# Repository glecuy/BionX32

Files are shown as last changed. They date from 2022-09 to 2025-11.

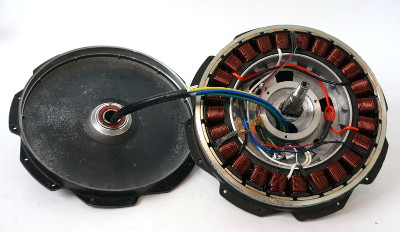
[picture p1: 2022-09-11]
bionx_motor.jpg

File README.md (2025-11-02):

# BionX32  stm32 controller for BionX ebike motor

The BionX motor has originally a built-in controller. This project aims to replace embedde electronics by an external controller.
Regular 24V controller with square waves doesn't provide good enough results, this is a new attempt with a FOC implementation.

## Project Content

3 phases output,

3 hall sensors input,

One Shunt current measurement,

Interface for S866 Display.

PAS input,

Brake input

Core code is generated thanks to ST micro graphical tools. (X-CUBE-MCSDK)
then adapted to STM32F103C8Tx

## Hardware description

STM32 module
MOSFET module
Main pcb
S866 display

## Credits  & Resources
STM32CubeIDE

STM32 MC SDK (motor control software development kit) : Gived up (Did not work for me)

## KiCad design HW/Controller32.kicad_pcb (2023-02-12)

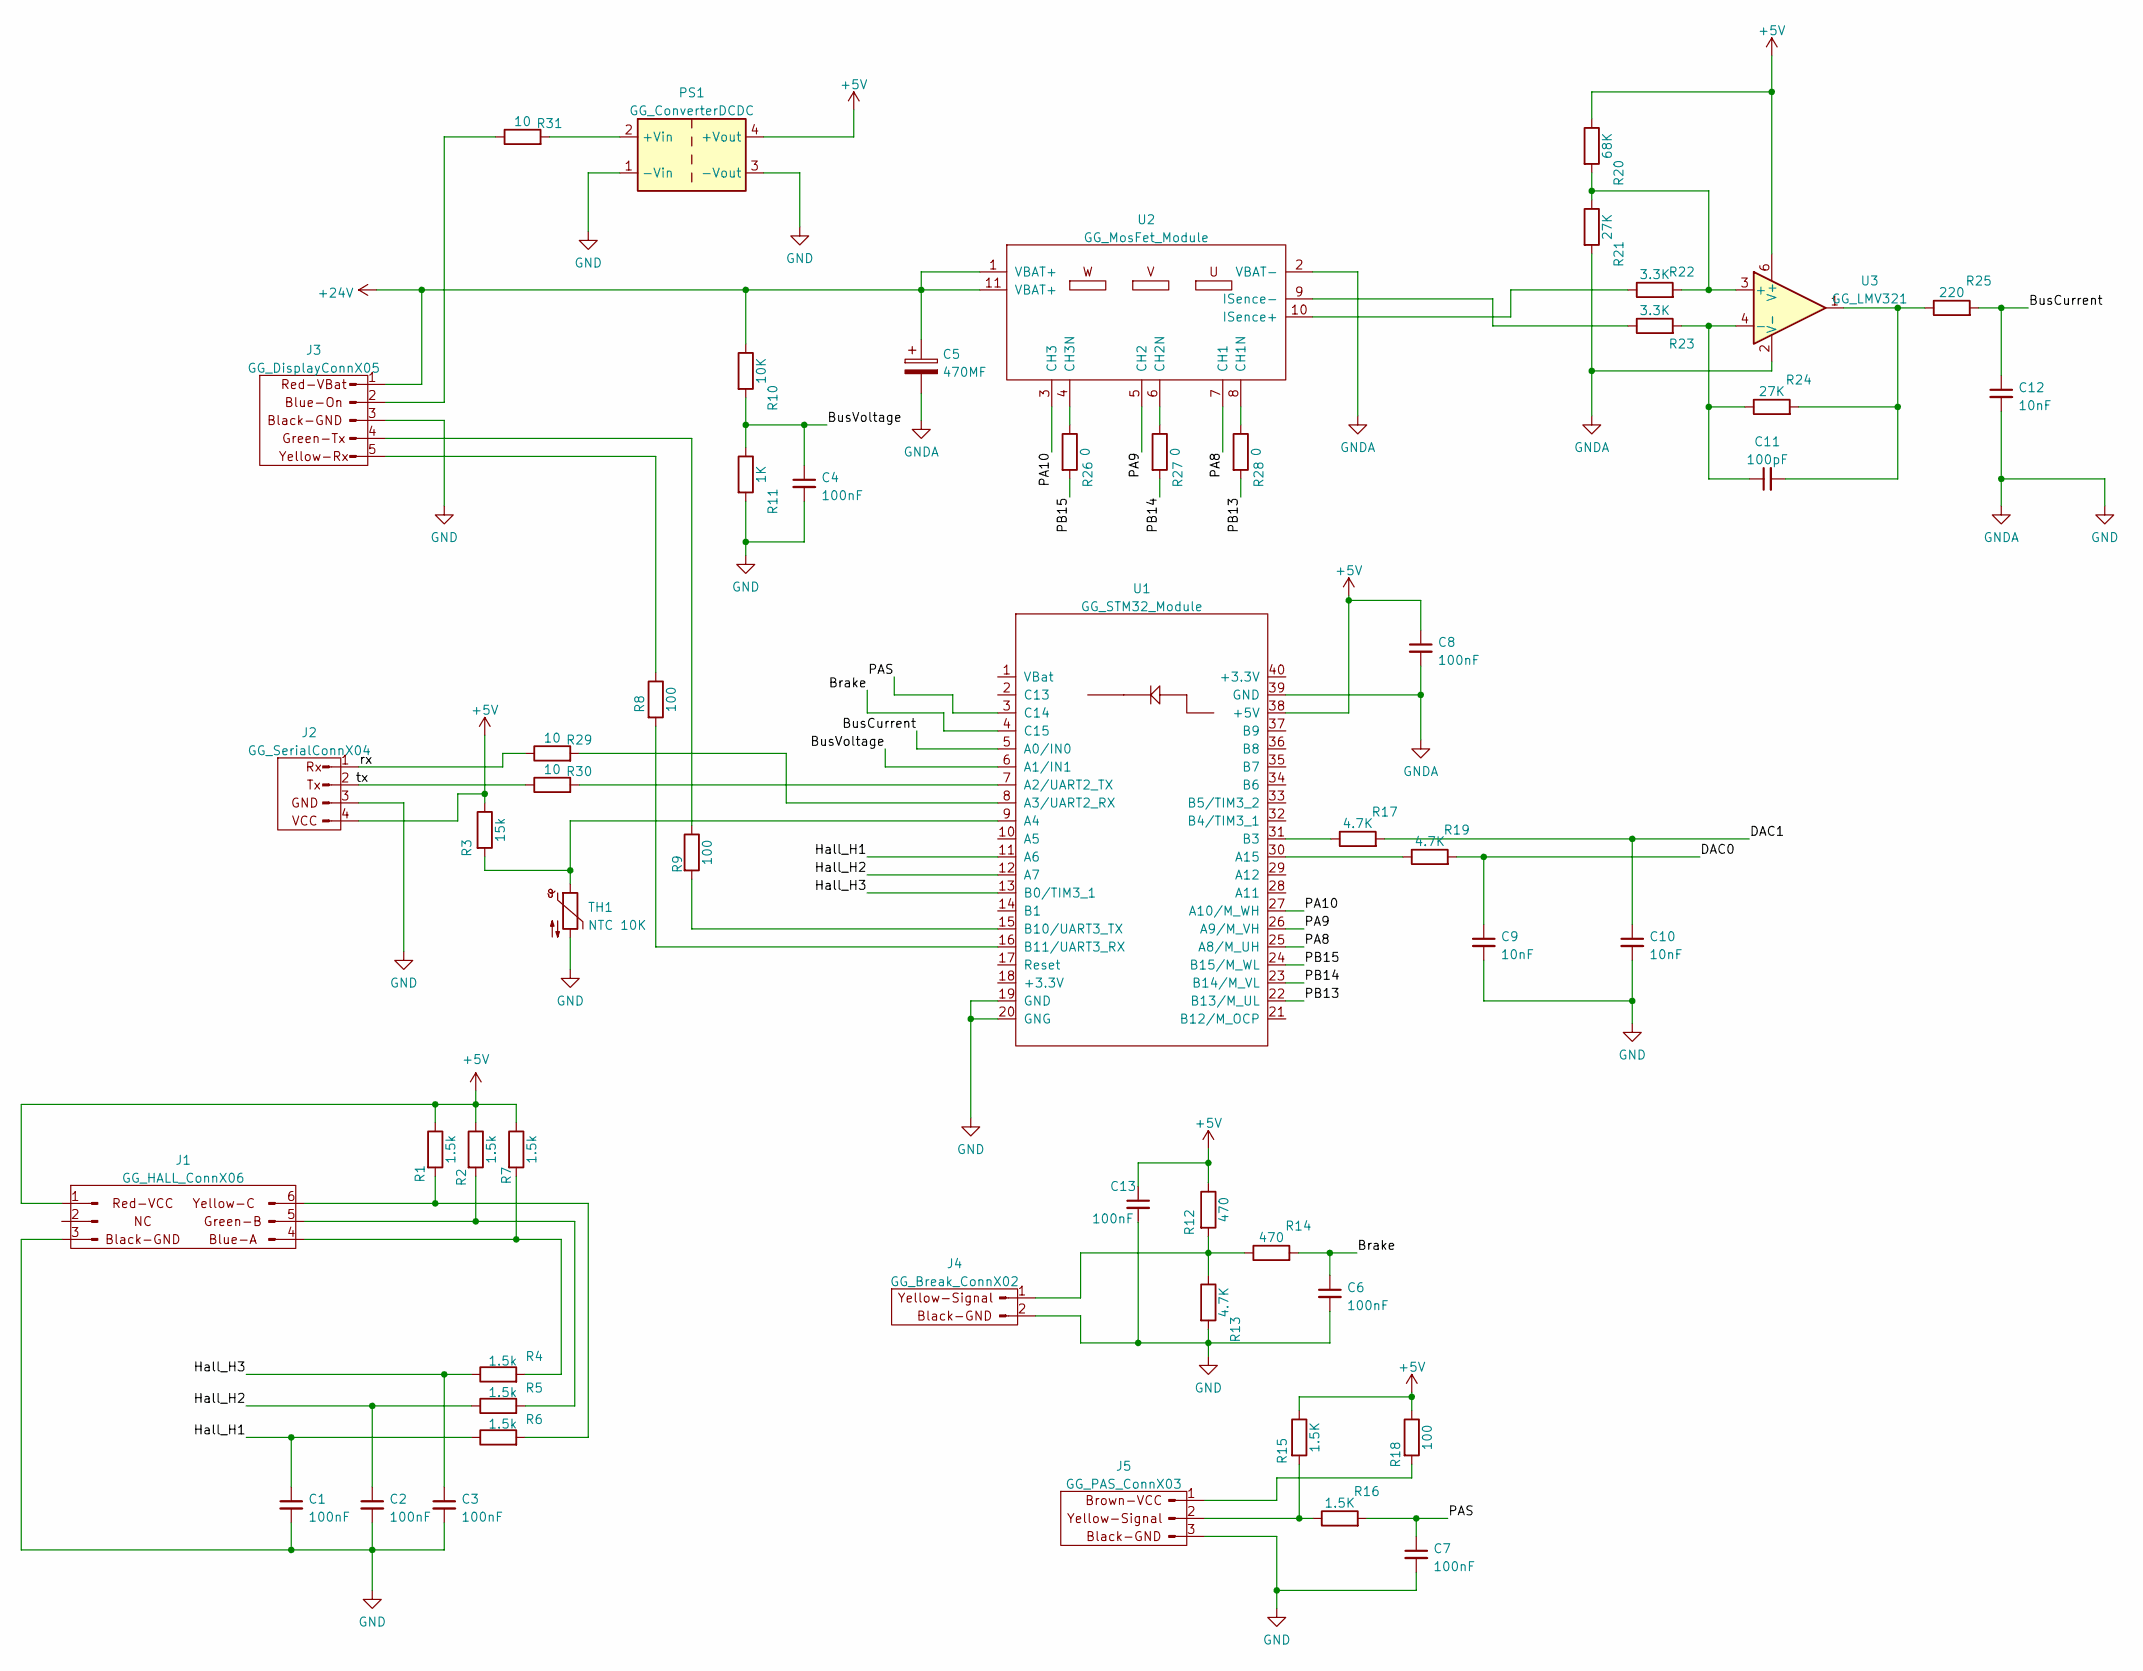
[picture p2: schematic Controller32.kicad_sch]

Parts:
C1, C2, C3, C4, C6, C7, C8, C13: 100nF; GG_C_0805
C5: 470MF; GG_CP_L30.0mm_D15.0mm_Horizontal
C9, C10, C12: 10nF; GG_C_0805
C11: 100pF; GG_C_0805
J1: GG_HALL_ConnX06; GG_6Wires_P2.54mm
J2: GG_SerialConnX04; GG_Serial04_P2.54mm
J3: GG_DisplayConnX05; GG_5Wires_P2.54mm
J4: GG_Break_ConnX02; GG_2Wires_P2.54mm
J5: GG_PAS_ConnX03; GG_3Wires_P2.54mm
PS1: GG_ConverterDCDC; GG_X0018_DCDC
R1, R2, R4, R5, R6, R7: 1.5k; GG_R_1206
R3: 15k; GG_R_1206
R8, R9, R18: 100; GG_R_1206
R10: 10K; GG_R_1206
R11: 1K; GG_R_1206
R12, R14: 470; GG_R_1206
R13, R17, R19: 4.7K; GG_R_1206
R15, R16: 1.5K; GG_R_1206
R20: 68K; GG_R_1206
R21, R24: 27K; GG_R_1206
R22, R23: 3.3K; GG_R_1206
R25: 220; GG_R_1206
R26, R27, R28: 0; GG_R_1206
R29, R30, R31: 10; GG_R_1206
TH1: NTC 10K; GG_2Wires_P2.54mm
U1: GG_STM32_Module; GG_STM32_DIP-40
U2: GG_MosFet_Module; GG_MOSFET_Moule
U3: GG_LMV321; SOT-23-6_Handsoldering

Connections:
+5V: C8.1, C13.1, J1.1, J2.4, PS1.4 (+Vout), R1.1, R2.1, R3.1, R7.1, R12.1, R15.1, R18.1, R20.1, U1.38 (+5V), U3.6 (V+)
+24V: C5.1, J3.1, R10.1, U2.1 (VBAT+), U2.11 (VBAT+)
/Brake: C6.1, R14.2, U1.4 (C15)
/BusCurrent: C12.1, R25.2, U1.5 (A0/IN0)
/BusVoltage: C4.1, R10.2, R11.1, U1.6 (A1/IN1)
/DAC0: C9.1, R19.2
/DAC1: C10.1, R17.2
/Hall_H1: C1.1, R6.1, U1.11 (A6)
/Hall_H2: C2.1, R5.1, U1.12 (A7)
/Hall_H3: C3.1, R4.1, U1.13 (B0/TIM3_1)
/PA8: U1.25 (A8/M_UH), U2.7 (CH1)
/PA9: U1.26 (A9/M_VH), U2.5 (CH2)
/PA10: U1.27 (A10/M_WH), U2.3 (CH3)
/PAS: C7.1, R16.2, U1.3 (C14)
/PB13: R28.2, U1.22 (B13/M_UL)
/PB14: R27.2, U1.23 (B14/M_VL)
/PB15: R26.2, U1.24 (B15/M_WL)
/rx: J2.1, R29.1
GND: C1.2, C2.2, C3.2, C4.2, C5.2, C6.2, C7.2, C8.2, C9.2, C10.2, C12.2, C13.2, J1.3, J2.3, J3.3, J4.2, J5.3, PS1.1 (-Vin), PS1.3 (-Vout), R11.2, R13.2, R21.2, TH1.2, U1.19 (GND), U1.20 (GNG), U1.39 (GND), U2.2 (VBAT-), U3.2 (V-)
unnamed: C11.1, R23.2, R24.1, U3.4 (-)
unnamed: C11.2, R24.2, R25.1, U3.1
unnamed: J1.4, R4.2, R7.2
unnamed: J1.5, R2.2, R5.2
unnamed: J1.6, R1.2, R6.2
unnamed: J2.2, R30.1
unnamed: J3.2, R31.1
unnamed: J3.4, R9.1
unnamed: J3.5, R8.1
unnamed: J4.1, R12.2, R13.1, R14.1
unnamed: J5.1, R18.2
unnamed: J5.2, R15.2, R16.1
unnamed: PS1.2 (+Vin), R31.2
unnamed: R3.2, TH1.1, U1.9 (A4)
unnamed: R8.2, U1.16 (B11/UART3_RX)
unnamed: R9.2, U1.15 (B10/UART3_TX)
unnamed: R17.1, U1.31 (B3)
unnamed: R19.1, U1.30 (A15)
unnamed: R20.2, R21.1, R22.2, U3.3 (+)
unnamed: R22.1, U2.10 (ISence+)
unnamed: R23.1, U2.9 (ISence-)
unnamed: R26.1, U2.4 (CH3N)
unnamed: R27.1, U2.6 (CH2N)
unnamed: R28.1, U2.8 (CH1N)
unnamed: R29.2, U1.8 (A3/UART2_RX)
unnamed: R30.2, U1.7 (A2/UART2_TX)

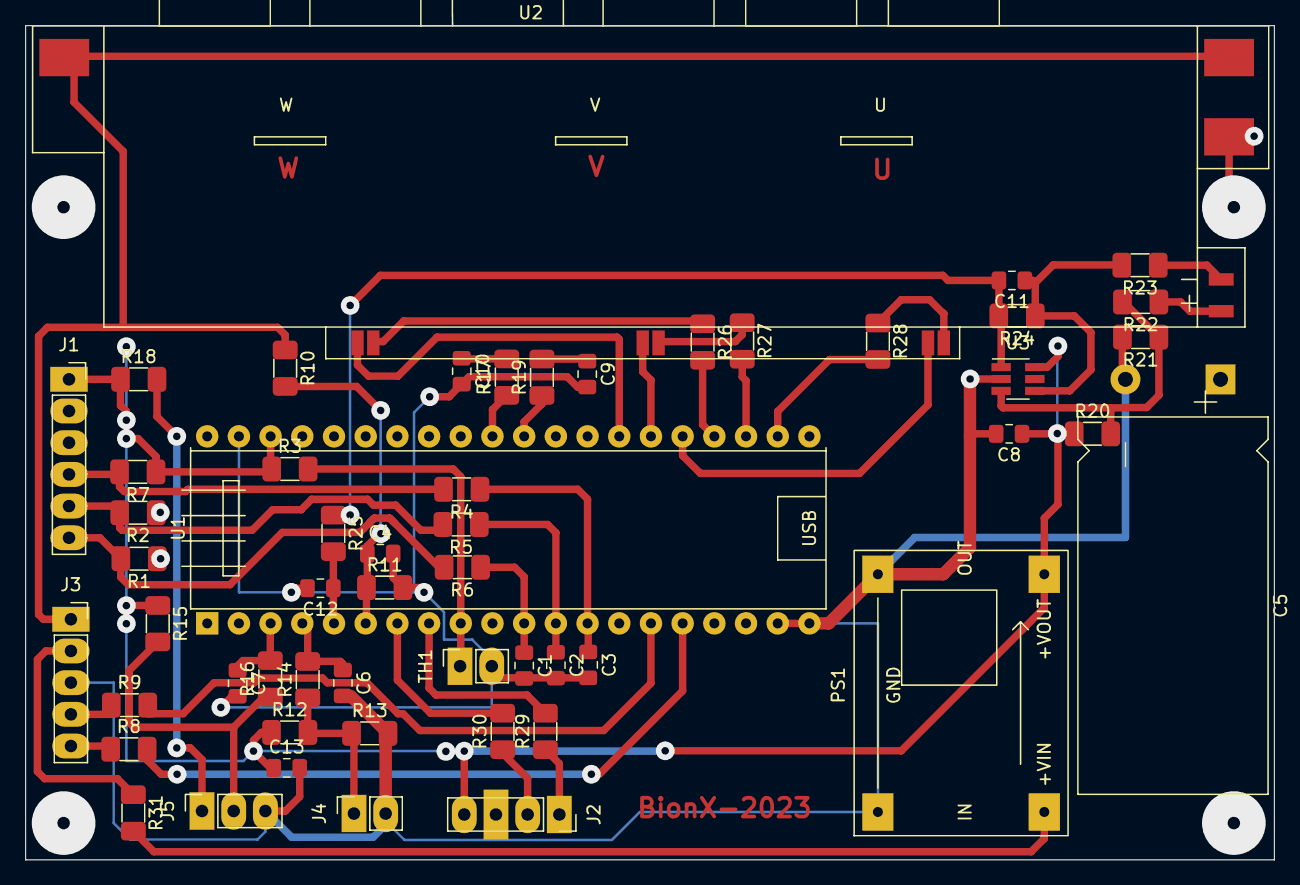
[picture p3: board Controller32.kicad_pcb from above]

Board: 2 copper layers, 100.1 x 66.9 mm, 54 parts (0 on the bottom side), 45 nets.

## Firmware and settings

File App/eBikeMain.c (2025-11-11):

/*
 *
 *
 ***********************************************************************/

#include <stdio.h>
#include <stdbool.h>
#include <stdlib.h>

#include "main.h"
#include "stm32f1xx_ll_gpio.h"

#include "UART_Printf.h"
#include "busVoltageSensor.h"
#include "eBikeMain.h"
#include "motorControl.h"

#include "display.h"

extern TIM_HandleTypeDef htim1;
extern TIM_HandleTypeDef htim2;
extern TIM_HandleTypeDef htim3;
extern TIM_HandleTypeDef htim4;
extern DMA_HandleTypeDef hdma_tim1_up;
extern DMA_HandleTypeDef hdma_tim1_ch4_trig_com;

extern ADC_HandleTypeDef hadc1;
//extern ADC_HandleTypeDef hadc2;

uint32_t ADC_ResultBuffer[4];


// Motor
static uint16_t PreviousHallState;
static uint32_t HallError;
static uint16_t HallTicks;
static uint32_t HallCycles;
static uint16_t PreviousHallTicks;

//static uint16_t SpaceSectorCnt;

static uint32_t BusVoltage, BoardTemperature, MotorTemperature;
static uint32_t PhaseCurrent;


static uint16_t HallState;

static inline void disable_pwm(void) {
  CLEAR_BIT(TIM1->BDTR, TIM_BDTR_MOE);
}

static inline void enable_pwm(void) {
  SET_BIT(TIM1->BDTR, TIM_BDTR_MOE);
}

static inline bool isSpaceVectorMode(void) {
    return ( HallTicks < 30000 && HallCycles > 100 );
    //return false;
}

void eBikeInit(void){
    GPIO_InitTypeDef GPIO_InitStruct = {0};

    // Start Timer 1
    if(HAL_TIM_Base_Start_IT(&htim1) != HAL_OK)
    {
        /* Counter Enable Error */
        Error_Handler();
    }

    HAL_TIM_PWM_Start(&htim1, TIM_CHANNEL_1);
    HAL_TIMEx_PWMN_Start(&htim1, TIM_CHANNEL_1); // turn on complementary channel
    HAL_TIM_PWM_Start(&htim1, TIM_CHANNEL_2);
    HAL_TIMEx_PWMN_Start(&htim1, TIM_CHANNEL_2);
    HAL_TIM_PWM_Start(&htim1, TIM_CHANNEL_3);
    HAL_TIMEx_PWMN_Start(&htim1, TIM_CHANNEL_3);

    //TIM1->CR2 = _VAL2FLD(TIM_CR2_MMS, 0b111); // OC1REF signal is used as trigger output (TRGO)
    //TIM1->CR2 = _VAL2FLD(TIM_CR2_MMS, 0b010); // The update event is selected as trigger output (TRGO)

#if 1
    // Start Timer 2 (DAC output)
    HAL_TIM_IC_Start_IT(&htim2, TIM_CHANNEL_1);
    //HAL_TIM_IC_Start_IT(&htim2, TIM_CHANNEL_2);
    //HAL_TIM_IC_Start_IT(&htim2, TIM_CHANNEL_3);

    // Start Timer 3
    //TIM3->PSC = 250;
    HAL_TIM_Base_Start_IT(&htim3);
    HAL_TIMEx_HallSensor_Start_IT(&htim3);
#endif

    //set initial PWM values
    TIM1->CCR1 = 1023;
    TIM1->CCR2 = 1023;
    TIM1->CCR3 = 1023;

    TIM1->CCR4 = 1;

    // App tick timer
    // See https://deepbluembedded.com/stm32-timer-calculator/
    // Updatefrequency = TIM clk/((PSC+1)*(ARR+1))
    //HAL_TIM_Base_Start_IT(&htim4);

    // ***TIM3 GPIO Configuration
    //PA6     ------> TIM3_CH1
    //PA7     ------> TIM3_CH2
    //PB0     ------> TIM3_CH3


    GPIO_InitStruct.Pin = Hall_H1_Pin|Hall_H2_Pin;
    GPIO_InitStruct.Mode = GPIO_MODE_INPUT;
    GPIO_InitStruct.Pull = GPIO_NOPULL;
    HAL_GPIO_Init(GPIOA, &GPIO_InitStruct);

    GPIO_InitStruct.Pin = Hall_H3_Pin;
    GPIO_InitStruct.Mode = GPIO_MODE_INPUT;
    GPIO_InitStruct.Pull = GPIO_NOPULL;
    HAL_GPIO_Init(Hall_H3_GPIO_Port, &GPIO_InitStruct);

    // Lock pins
    LL_GPIO_LockPin(Hall_H3_GPIO_Port, Hall_H3_Pin);
    LL_GPIO_LockPin(Hall_H1_GPIO_Port, Hall_H1_Pin);
    LL_GPIO_LockPin(Hall_H2_GPIO_Port, Hall_H2_Pin);

    MotorDriveInit();

    displayInit();
}

void HAL_TIM_OC_DelayElapsedCallback(TIM_HandleTypeDef *htim){
    if ( htim->Instance == TIM3 ){
        //BlueLED_toggle();
    }
}

void HAL_TIM_PWM_PulseFinishedCallback(TIM_HandleTypeDef *htim){
    if ( htim->Instance == TIM3 ){
        //BlueLED_toggle();
    }
}


/**
  * Called from TIM3 IRQHandler
  * When no change is detected on Hall sensors lines
  */
void HAL_TIM3_Callback(void){
    if ((TIM3->SR & (TIM_FLAG_UPDATE)) == (TIM_FLAG_UPDATE)){
        HallTicks = 65535;
    }

}


// Validate hall state against previous state
//
uint16_t ValidateHallState( uint16_t state ){
    uint16_t validated = state;

    if ( HallTicks > MIN_STABLE_WHEEL_SPEED_TICKS ){
        return validated;
    }

    switch (PreviousHallState){
        case 1:
            validated = 3;
            break;

        case 3:
            validated = 2;
            break;

        case 2:
            validated = 6;
            break;

        case 6:
            validated = 4;
            break;

        case 4:
            validated = 5;
            break;

        case 5:
            validated = 1;
            break;
    }
    if ( validated != state ){
        HallError++;
    }
    //return state;
    return validated;
}

int16_t hallTable[] = {0xFF, 1, 5, 6, 3, 2, 4, 0xFF};

uint16_t ReadHallState( void ){
    uint32_t hall1, hall2, hall3;
    uint16_t state;

    hall3 = LL_GPIO_ReadInputPort( Hall_H2_GPIO_Port );
    hall3 >>= 5;
    hall2 = hall3;
    hall3 &= 0x04;
    hall2 &= 0x02;
    hall1  = LL_GPIO_ReadInputPort( Hall_H3_GPIO_Port ) & 0x01;
    state = (uint16_t)(hall3 | hall2 | hall1);

    return state;
}

/**
  * Manages HALL changes
  */
void HAL_TIM_IC_CaptureCallback(TIM_HandleTypeDef* htim){
    uint16_t HallState0;

    //BlueLED_on();

    //BlueLED_toggle();
    // TODO Improve Hardware noise filtering !
    HallState0 = ReadHallState();

    __ASM volatile ("NOP");
    __ASM volatile ("NOP");
    __ASM volatile ("NOP");
    __ASM volatile ("NOP");

    HallState = ReadHallState();

    HallCycles++;

    if  ( HallState0 != HallState ){
        HallError++;
    }


    // Store Tim3 ticks value since previous change
    HallTicks = TIM3->CCR1;

    if ( HallState == 1 ){
        BlueLED_toggle();
    }


    //HallState = ValidateHallState( HallState );
    int16_t sector = hallTable[HallState];
    SetPhasesPwm(sector);
#if 0
    if ( ! isSpaceVectorMode() ){
        switch (HallState){
            case 1:
                //Probe01_on();
                SetPhasesPwm(STATE_PM0);
                break;

            case 3:
                //Probe01_off();
                SetPhasesPwm(STATE_0MP);
                break;

            case 2:
                //Probe01_off();
                SetPhasesPwm(STATE_M0P);
                break;

            case 6:
                //Probe01_off();
                SetPhasesPwm(STATE_MP0);
                break;

            case 4:
                //Probe01_off();
                SetPhasesPwm(STATE_0PM);
                break;

            case 5:
                //Probe01_off();
                SetPhasesPwm(STATE_P0M);
                break;
            default:
                HallError++;
                break;
        }
    }
#endif

    PreviousHallState = HallState;
    PreviousHallTicks = HallTicks;

    //BlueLED_off();
}



void HAL_ADC_ConvCpltCallback(ADC_HandleTypeDef* hadc){
    if ( hadc->Instance == ADC1 ) {
        //BlueLED_toggle();
        BusVoltage       = ADC_ResultBuffer[0];
        MotorTemperature = ADC_ResultBuffer[1];
        BoardTemperature = ADC_ResultBuffer[2];  // Internal Sensor
    }
}


void HAL_ADCEx_InjectedConvCpltCallback(ADC_HandleTypeDef* hadc)
{
    //BlueLED_on();
    PhaseCurrent = HAL_ADCEx_InjectedGetValue(&hadc1, ADC_INJECTED_RANK_1);  // Read The Injected Channel Result
    //BlueLED_off();
}

const char * str_BusVoltage( uint32_t voltage){
    static char strVoltage[16];

    snprintf(strVoltage, 16, "%02lu.%lu", voltage/1000, voltage%1000 );
    return strVoltage;
}

void eBikeMainLoop(void){
    uint16_t wheelticks=0;

    uint32_t prev100Tick, prev10Tick, tick;

    prev10Tick  = 0;
    prev100Tick = 0;

    HAL_ADC_Start_DMA(&hadc1, ADC_ResultBuffer, 3);
    HAL_Delay(10);

    HAL_ADCEx_InjectedStart_IT(&hadc1); // Start ADC Conversion (Injected Channel, Tim1-PWM-Triggered, Interrupt Mode)
    // Inject ADC1 measurement to get peak value of the current.
    TIM1->CCR4 = 1500;

    // Start TIM4
    HAL_TIM_Base_Start_IT(&htim4);

    //UART_printf( "ARR = %u\r\n", TIM1->ARR );
    UART_printf( "CR2 = %04X\r\n", TIM1->CR2 );

     TIM4->ARR = 300;

    while(1){
        tick = HAL_GetTick();

        if ( tick > (prev10Tick + 100) ){
            prev10Tick = tick;
            HAL_NVIC_DisableIRQ(TIM3_IRQn);
            wheelticks = HallTicks;
            HAL_NVIC_EnableIRQ(TIM3_IRQn);

            ///__HAL_TIM_SET_AUTORELOAD( &htim4, (wheelticks/16) );

            displaySetWheelTime( WHEEL_SPEED_RPMx10(wheelticks) );

            // Display console In/Out
            displayService();

            // Manage Drive parameters
            MotorDriveService();
        }
        if ( tick > (prev100Tick + 1000) ){
            prev100Tick = tick;
            if ( wheelticks == 65535 ){
                HAL_TIM_IC_CaptureCallback(NULL);
                HallCycles = 0;
            }

            displayUpdate();

            UART_printf( "HallState = %u WheelSpeed = %u (%u)-%u\r\n", PreviousHallState, WHEEL_SPEED_KPH(wheelticks), wheelticks, HallCycles);
            // Bus voltage milliVolts
            BusVoltage       = (BusVoltage*((ADC_REFERENCE_VOLTAGE*10*1000)/4096))/VBUS_PARTITIONING_FACTORx10000;

            if ( PhaseCurrent > 2250 )
                PhaseCurrent     = PhaseCurrent - 2250;
            else
                PhaseCurrent     = 0;

            //UART_printf( "PhaseCurrent=%u\r\n", PhaseCurrent );
            //UART_printf( "BusVoltage=%s, PhaseCurrent=%u, MotorTemperature=%u, BoardTemperature=%u\r\n", str_BusVoltage(BusVoltage), PhaseCurrent, MotorTemperature, BoardTemperature);
        }
    }

}

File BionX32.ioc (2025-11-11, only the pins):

Mcu.UserName=STM32F103C8Tx
PA0-WKUP.Signal=ADCx_IN0
PA1.Signal=ADCx_IN1
PA10.Signal=S_TIM1_CH3
PA11.Signal=S_TIM1_CH4
PA13.Signal=SYS_JTMS-SWDIO
PA14.Signal=SYS_JTCK-SWCLK
PA15.Signal=S_TIM2_CH1_ETR
PA2.Signal=USART2_TX
PA3.Signal=USART2_RX
PA4.Signal=ADCx_IN4
PA5.GPIO_Label=Probe01
PA5.Signal=GPIO_Output
PA6.GPIO_Label=Hall_H1
PA6.Signal=S_TIM3_CH1
PA7.GPIO_Label=Hall_H2
PA7.Signal=S_TIM3_CH2
PA8.Signal=S_TIM1_CH1
PA9.Signal=S_TIM1_CH2
PB0.GPIO_Label=Hall_H3
PB0.Signal=S_TIM3_CH3
PB10.Signal=USART3_TX
PB11.Signal=USART3_RX
PB13.Signal=TIM1_CH1N
PB14.Signal=TIM1_CH2N
PB15.Signal=TIM1_CH3N
PB3.Signal=S_TIM2_CH2
PC13-TAMPER-RTC.GPIO_Label=BlueLED
PC13-TAMPER-RTC.Signal=GPIO_Output
PD0-OSC_IN.Signal=RCC_OSC_IN
PD1-OSC_OUT.Signal=RCC_OSC_OUT

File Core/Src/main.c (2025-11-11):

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
/* Includes ------------------------------------------------------------------*/
#include "main.h"

/* USER CODE BEGIN Includes */
#include "UART_Printf.h"
#include "motorControl.h"
#include "busVoltageSensor.h"
#include "eBikeMain.h"

#include "display.h"

/* USER CODE END Includes */

ADC_HandleTypeDef hadc1;
DMA_HandleTypeDef hdma_adc1;

TIM_HandleTypeDef htim1;
TIM_HandleTypeDef htim2;
TIM_HandleTypeDef htim3;
TIM_HandleTypeDef htim4;

UART_HandleTypeDef huart2;
UART_HandleTypeDef huart3;

void SystemClock_Config(void);
static void MX_GPIO_Init(void);
static void MX_DMA_Init(void);
static void MX_USART2_UART_Init(void);
static void MX_USART3_UART_Init(void);
static void MX_ADC1_Init(void);
static void MX_TIM1_Init(void);
static void MX_TIM2_Init(void);
static void MX_TIM3_Init(void);
static void MX_TIM4_Init(void);
static void MX_NVIC_Init(void);
/* USER CODE BEGIN PFP */
static void BlueLed_Flashing(int n0, int n1);
/* USER CODE END PFP */

/**
  * @brief  The application entry point.
  * @retval int
  */
int main(void)
{
  /* MCU Configuration--------------------------------------------------------*/

  /* Reset of all peripherals, Initializes the Flash interface and the Systick. */
  HAL_Init();

  /* Configure the system clock */
  SystemClock_Config();

  /* Initialize all configured peripherals */
  MX_GPIO_Init();
  MX_DMA_Init();
  MX_USART2_UART_Init();
  MX_USART3_UART_Init();
  MX_ADC1_Init();
  MX_TIM1_Init();
  MX_TIM2_Init();
  MX_TIM3_Init();
  MX_TIM4_Init();

  /* Initialize interrupts */
  MX_NVIC_Init();
  /* USER CODE BEGIN 2 */

  UART_printf( "******* BIONX MOTOR version 1.00 *********\r\n");

  eBikeInit();

  /* USER CODE END 2 */

  /* Infinite loop */
  /* USER CODE BEGIN WHILE */
  while (1)
  {
    eBikeMainLoop();
    /* USER CODE END WHILE */

    /* USER CODE BEGIN 3 */
    Error_Handler();
  }
  /* USER CODE END 3 */
}

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
/* USER CODE BEGIN 4 */
void HAL_UART_TxCpltCallback(UART_HandleTypeDef *huart)
{
    if ( huart == &huart2 ){
        PrintfEndOfTx();
    }
    if ( huart == &huart3 ){
        displayEndOfTx();
    }
}

void HAL_UART_RxCpltCallback(UART_HandleTypeDef *huart){
    if (huart->Instance == USART3){
        displayEndOfRx();
    }
}



/* Debug purpose endless function */
void BlueLed_Flashing(int n0, int n1)
{
    n0 *= 1000;
    n1 *= 1000;
  while (1)
  {
      int i;
      for ( i=0 ; i< n0 ; i++ ){
        BlueLED_on();
        BlueLED_on();
      }
      for ( i=0 ; i< n1 ; i++ ){
        BlueLED_off();
        BlueLED_off();
      }
  }
}

/* USER CODE END 4 */
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


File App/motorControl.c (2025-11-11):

#include "main.h"
#include "eBikeMain.h"
#include "motorControl.h"

#include "stm32f1xx_hal_tim.h"

#include "UART_Printf.h"

static uint16_t CurrentAssistLevel;
static uint16_t AssistLevel;

// Enable or not printf traces
void UART_printf(const char *fmt, ...);
#define printf UART_printf
//#define printf (void)


void MotorDriveInit(void){
    CurrentAssistLevel = 0;
    AssistLevel = 0;
}

void MotorDriveService(void){
    if ( AssistLevel > CurrentAssistLevel ){
        CurrentAssistLevel++;
    }
    if ( AssistLevel < CurrentAssistLevel ){
        CurrentAssistLevel--;
    }
    if ( CurrentAssistLevel == 0 ){
        DisablePWMs();
    }
    else{
        EnablePWMs();
    }
}


#ifdef TEST_SINE
#define NUM_POINTS 66
#define SIN_TABLE_REF 512
// Phases Relative position
#define TIME_OFFSET_A  (0)
#define TIME_OFFSET_B  (NUM_POINTS / 3)
#define TIME_OFFSET_C  (2 * NUM_POINTS / 3)

int16_t table_sin[NUM_POINTS] = {
0,48,96,144,190,234,276,316,352,386,416,442,465,483,497,506,510,510,506,497,483,465,
442,416,386,352,316,276,234,190,144,96,48,0,-48,-96,-144,-190,-234,-276,-316,-352,-386,-416,
-442,-465,-483,-497,-506,-510,-510,-506,-497,-483,-465,-442,-416,-386,-352,-316,-276,-234,-190,-144,-96,-48
};


void UpdateTestSinePwm(void){
    static uint16_t counter = 0;

    int16_t MaxAmplitude = TIM1->ARR;
    int16_t Offset = MaxAmplitude/2;
    int16_t Amplitude = MaxAmplitude/10;


    TIM1->CCR1 = (uint16_t)(Offset+(Amplitude * table_sin[(counter + TIME_OFFSET_A) % NUM_POINTS])/SIN_TABLE_REF);
    TIM1->CCR2 = (uint16_t)(Offset+(Amplitude * table_sin[(counter + TIME_OFFSET_B) % NUM_POINTS])/SIN_TABLE_REF);
    TIM1->CCR3 = (uint16_t)(Offset+(Amplitude * table_sin[(counter + TIME_OFFSET_C) % NUM_POINTS])/SIN_TABLE_REF);

    counter++;
}

#endif // TEST_SINE


/*
 * Set level of assistance.
 * Scale is 0 to 100
 *****************************************/
uint16_t SetAssistLevel( uint16_t level ){
    // TODO fine tune scale
    if ( level <= 100 )
        AssistLevel = level;
    else
        AssistLevel = 0;

    printf("AssistLevel = %d %%\r\n", AssistLevel);
    return AssistLevel;
}


/*
 * Space vector modulation (Sinewave)
 * Space Vector PWM Intro — Switchcraft (pdf doc)
 * Microchip AN3453
 */

/* Sinusoidal Data Look-Up Table (16 values)
 */
#define TABLE_REF 400
uint16_t PWM_1[16] = {0, 0, 0, 0, 0, 0, 0, 0, 0, 0, 0, 0, 0, 0, 0, 0};
uint16_t PWM_2[16] = {5, 54, 107, 160, 208, 259, 310, 355, 401, 448, 487, 529, 568, 601, 635, 666};
uint16_t PWM_3[16] = {690, 715, 736, 753, 769, 780, 788, 794, 794, 793, 787, 779, 767, 751, 733, 713};
uint16_t PWM_4[16] = {690, 715, 734, 753, 769, 779, 788, 794, 795, 793, 787, 779, 767, 751, 734, 713};
uint16_t PWM_5[16] = {687, 661, 629, 594, 561, 521, 479, 439, 393, 345, 301, 250, 198, 151, 98, 44};
uint16_t PWM_6[16] = {0, 0, 0, 0, 0, 0, 0, 0, 0, 0, 0, 0, 0, 0, 0, 0};
void SetPhasesSvPwm(int16_t sector, int16_t pos){

    int16_t MaxAmplitude = TIM1->ARR;
    int16_t Amplitude = ((MaxAmplitude * CurrentAssistLevel)/100)/2;

    Amplitude /= 3;

    if ( pos > 15 ){
        pos = 15;
    }

    switch( sector ){
        case SECTOR1:
            TIM1->CCR1 = (Amplitude * PWM_3[pos])/TABLE_REF;
            TIM1->CCR2 = (Amplitude * PWM_5[pos])/TABLE_REF;
            TIM1->CCR3 = (Amplitude * PWM_1[pos])/TABLE_REF;
        break;
        case SECTOR2:
            TIM1->CCR1 = (Amplitude * PWM_2[pos])/TABLE_REF;
            TIM1->CCR2 = (Amplitude * PWM_4[pos])/TABLE_REF;
            TIM1->CCR3 = (Amplitude * PWM_6[pos])/TABLE_REF;
        break;
        case SECTOR3:
            TIM1->CCR1 = (Amplitude * PWM_1[pos])/TABLE_REF;
            TIM1->CCR2 = (Amplitude * PWM_3[pos])/TABLE_REF;
            TIM1->CCR3 = (Amplitude * PWM_5[pos])/TABLE_REF;
        break;
        case SECTOR4:
            TIM1->CCR1 = (Amplitude * PWM_6[pos])/TABLE_REF;
            TIM1->CCR2 = (Amplitude * PWM_2[pos])/TABLE_REF;
            TIM1->CCR3 = (Amplitude * PWM_4[pos])/TABLE_REF;
        break;
        case SECTOR5:
            TIM1->CCR1 = (Amplitude * PWM_5[pos])/TABLE_REF;
            TIM1->CCR2 = (Amplitude * PWM_1[pos])/TABLE_REF;
            TIM1->CCR3 = (Amplitude * PWM_3[pos])/TABLE_REF;
        break;
        case SECTOR6:
            TIM1->CCR1 = (Amplitude * PWM_4[pos])/TABLE_REF;
            TIM1->CCR2 = (Amplitude * PWM_6[pos])/TABLE_REF;
            TIM1->CCR3 = (Amplitude * PWM_2[pos])/TABLE_REF;
        break;
        default:
            Error_Handler();
            break;
    }
}

/*
 * Trapezoidal driving mode for motor phases
 * Two options
 *  All 3 generators are active (switching)
 * One over 3 generators is set to 0 (No switching), supposed to reduce loss
 *
 **********************************************************************/
void SetPhasesPwm(int16_t step){

    int16_t MaxAmplitude = TIM1->ARR;
    int16_t Offset = MaxAmplitude/2;
    int16_t Amplitude = ((MaxAmplitude * CurrentAssistLevel)/100)/2;

    //Amplitude /= 3;

#if 0  // TODO
    switch( step ){
        case STATE_PM0:
            TIM1->CCR1 = Offset+Amplitude;
            TIM1->CCR2 = Offset-Amplitude;
            TIM1->CCR3 = Offset;
        break;
        case STATE_P0M:
            TIM1->CCR1 = Offset+Amplitude;
            TIM1->CCR2 = Offset;
            TIM1->CCR3 = Offset-Amplitude;
        break;
        case STATE_0PM:
            TIM1->CCR1 = Offset;
            TIM1->CCR2 = Offset+Amplitude;
            TIM1->CCR3 = Offset-Amplitude;
        break;
        case STATE_MP0:
            TIM1->CCR1 = Offset-Amplitude;
            TIM1->CCR2 = Offset+Amplitude;
            TIM1->CCR3 = Offset;
        break;
        case STATE_M0P:
            TIM1->CCR1 = Offset-Amplitude;
            TIM1->CCR2 = Offset;
            TIM1->CCR3 = Offset+Amplitude;
        break;
        case STATE_0MP:
            TIM1->CCR1 = Offset;
            TIM1->CCR2 = Offset-Amplitude;
            TIM1->CCR3 = Offset+Amplitude;
        break;
        default:
            Error_Handler();
            break;
    }
#else
    switch( step ){
        case STATE_PM0:
            TIM1->CCR1 = 2 * Amplitude;
            TIM1->CCR2 = 0;
            TIM1->CCR3 = Amplitude;
        break;
        case STATE_P0M:
            TIM1->CCR1 = 2 * Amplitude;
            TIM1->CCR2 = Amplitude;
            TIM1->CCR3 = 0;
        break;
        case STATE_0PM:
            TIM1->CCR1 = Amplitude;
            TIM1->CCR2 = 2 * Amplitude;
            TIM1->CCR3 = 0;
        break;
        case STATE_MP0:
            TIM1->CCR1 = 0;
            TIM1->CCR2 = 2 * Amplitude;
            TIM1->CCR3 = Amplitude;
        break;
        case STATE_M0P:
            TIM1->CCR1 = 0;
            TIM1->CCR2 = Amplitude;
            TIM1->CCR3 = 2 * Amplitude;
        break;
        case STATE_0MP:
            TIM1->CCR1 = Amplitude;
            TIM1->CCR2 = 0;
            TIM1->CCR3 = 2 * Amplitude;
        break;
        default:
            Error_Handler();
            break;
    }
#endif

}

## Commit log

2022-09-11 Initial code, UART_Printf, s866 com OK
2022-09-14 New generated code for motor control
2022-09-17 revert communication with display (NOT FIXED)
    [display_s866.c, main.c, main.h]
2022-09-25 Fix and tune display Rx Tx, start MC interface
    [display_s866.c, main.c]
2022-10-01 Add ADC voltage and temperature
2023-02-12 Update from MotorSDK, implement PAS input
    [Controller32.kicad_pcb, Controller32.kicad_sch, Controller32.sch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]
2025-11-02 Restart project without ST motor SDK - Back to a simpler 6 steps driving mode

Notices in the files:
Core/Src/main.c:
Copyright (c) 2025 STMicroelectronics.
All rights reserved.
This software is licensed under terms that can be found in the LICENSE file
